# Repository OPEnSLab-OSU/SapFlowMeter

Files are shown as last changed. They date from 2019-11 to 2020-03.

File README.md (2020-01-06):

# Analysis of Sapflow Data

We are using python for post-processing and data analysis.

You should have the following installed:
- Python 3
- Pandas
- Numpy
- Matplotlib

You can find the recorded data at 
[web.engr.oregonstate.edu/~hornm/data/](http://web.engr.oregonstate.edu/~hornm/data/)

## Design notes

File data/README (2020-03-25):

This folder contains data from our sapflow probes.
In general, files that say "log" are temperature data, and files that say "sapflow" have calculated data.

tree1 is a spruce, with data captured using the MAX38165 RTD amplifier

tree4 is the same rhodedendron, using the MCP3432 ADC and a wheatstone bridge to get temeprature.

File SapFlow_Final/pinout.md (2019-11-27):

# Pinout of Feather M0 LoRa

**Left**

|Pin  |Signal|Peripheral|
|-----|---|---|
|RST  | Reset|
|3V | 3.3V | Voltage regulator |
|ARef | ARef | ADC |
|GND  |
|A0 |
|A1 |
|A2 |
|A3 |
|A4 |CS |MAX RTD sensor #2|
|A5 |CS |MAX RTD sensor #1|
|24 |SCK  |SPI|
|23 |MOSI |SPI|
|22 |MISO |SPI|
|0 |RX |Serial|
|1 |TX |Serial|
|DIO1 | ??? | LoRa |

**Right**

|Pin  |Signal|Peripheral|
|-----|---|---|
| 20 | SDA |I2C|
| 21 | SCL |I2C|
| 5  | 3.3_En| Power out (Pull low to enable)|
| 6  | 5v_En | Power out (Pull high to enable)|
| 9  |
| 10 | CS| SD Card on Hypno|
| 11 | Heat | Relay |
| 12 | RTC_interrupt |Real-time clock (used for alarms)|
| 13 | Status | LED |
| 5V | USB | Power in |
| En | Enable | Voltage Regulator |
| Bat| 3.7V | Battery |

**Pins dedicated to LoRa:**

|Pin  | Signal |
|-----|---|
|D3 | IRQ |
|D4 | RST |
|D8 | CS  |
|DIO1 | ??? |
|DIO2 | ??? |
|DIO3 | ??? |
|DIO5 | ??? |
Note: LoRa shares the SPI peripheral, but with a seperate chip select.

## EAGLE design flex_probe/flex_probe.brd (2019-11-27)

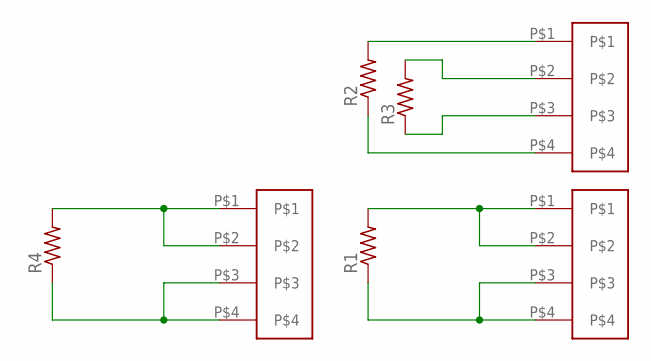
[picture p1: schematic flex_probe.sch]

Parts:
R1, R2, R3, R4: R-US_R0603; R0603
U$1, U$2, U$3: CONN_1X4; 4PAD

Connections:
unnamed: R1.2, U$1.P$1, U$1.P$2
unnamed: R1.1, U$1.P$3, U$1.P$4
unnamed: R2.1, U$2.P$4
unnamed: R3.2, U$2.P$2
unnamed: R3.1, U$2.P$3
unnamed: R2.2, U$2.P$1
unnamed: R4.2, U$3.P$1, U$3.P$2
unnamed: R4.1, U$3.P$3, U$3.P$4

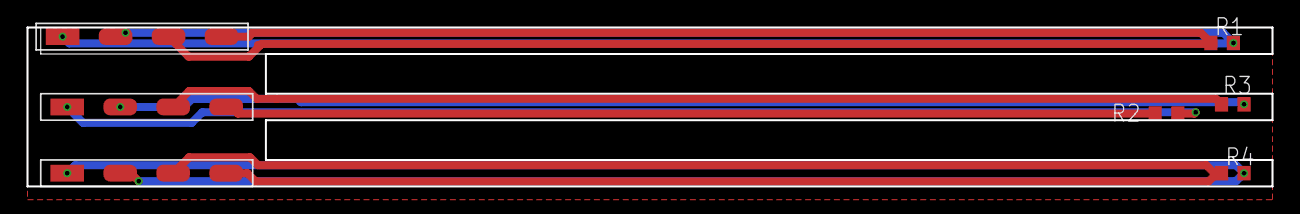
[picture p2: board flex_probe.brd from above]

Board: 2 copper layers, 94.0 x 12.0 mm, 7 parts (0 on the bottom side), 8 nets.

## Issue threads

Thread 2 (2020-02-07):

Need Error System

kamocat, 2020-02-07:
We need an error system on the feather, preferrably to post to Twitter.
Things we want to detect:
- SD card hanging
- Measurement errors (max and min temperature measured?)
- Bad reading from scale
- Low battery?
- Malformed JSON

kamocat, 2020-02-08:
We can use the watchdog timer to catch when things hang. The trick will be skipping a hanging function and continuing. Is there a way to have persistent variables after a watchdog reset? Or is there a way to return to a place different from where you started? ( Basically, save the stack pointer and skip over the problem function)

kamocat, 2020-02-08:
I'm envisioning a bitmask for each error, so known malfunctioning hardware will cause the appropriate function to be skipped.
For example, removing the SD card shouldn't cause the program to hang but should cause it to skip the steps for initializing the SD card. It should send a warning to Twitter about the issue.

prototypicalpro, 2020-02-10:
As you mentioned, the trick is exiting the function that hung without resetting the program. Greyston mentions this works on ARM: https://en.wikipedia.org/wiki/Setjmp.h , I'd be a bit scared to try it from an interrupt though. Another solution proposed by Atmel is writing your state to flash and then recovering it on reset: http://ww1.microchip.com/downloads/en/AppNotes/Atmel-42393-SAMD-Debugging-Watchdog-Timer-Reset_ApplicationNote_AT09381.pdf . This would also have the benefit of creating a "trace" of where the program failed.

kamocat, 2020-02-27:
Pull request #3 partially fixes this by providing a method for logging crashes.
We haven't yet implemented any sort of error reporting through Twitter, although this is our eventual goal.

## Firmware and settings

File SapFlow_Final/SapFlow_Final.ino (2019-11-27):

///////////////////////////////////////////////////////////////////////////////

// This program samples lots of temperature data from a tree to measure the sap flow.
///////////////////////////////////////////////////////////////////////////////

#define ALARM_PIN 12
#define HEATER 11

#include <OPEnS_RTC.h>
#include <LowPower.h>
#include <sdios.h> //for ArduinoOutStream

#include <SPI.h>
#include "SdFat.h"
#include "sdios.h"
#include <Adafruit_MAX31865.h>

Adafruit_MAX31865 rtd1 = Adafruit_MAX31865(A4);
Adafruit_MAX31865 rtd2 = Adafruit_MAX31865(A5);

#define RREF 430.0
#define RNOMINAL 100.0

ArduinoOutStream cout(Serial);

// Instance of our RTC
RTC_DS3231 rtc_ds;

// Time used for state transitions
volatile uint32_t event_time;

// SD chip select pin.  Be sure to disable any other SPI devices such as Enet.
const uint8_t chipSelect = 10;

// Interval between data records in milliseconds.
// The interval must be greater than the maximum SD write latency plus the
// time to acquire and write data to the SD to avoid overrun errors.
// Run the bench example to check the quality of your SD card.
const uint32_t SAMPLE_INTERVAL_MS = 1000;

SdFat sd; // File system object.

/* Checks if the filename exists.
* If so, appends an integer.
* Returns the new filename it came up with.*/
String newfile( String fname, String suffix=".csv" ){
  String temp = fname + suffix;
  int i = 0;
  while(sd.exists(temp.c_str())){
    ++i;
    char ones = i%10 + '0';
    char tens = i/10 + '0';
    temp = fname + '(' + tens + ones + ')' + suffix;
  }
  return temp;
}

// Stores samples and relative time.
// Adapt this datatype to your measurement needs.
class sample{
  private:
  float channel1;
  float channel2;
  DateTime t;

  public:
  sample( Adafruit_MAX31865 r1, Adafruit_MAX31865 r2 ){
    t = rtc_ds.now();
    r1.readRTD();
    r2.readRTD();
    channel1 = r1.temperature(RNOMINAL, RREF);
    channel2 = r2.temperature(RNOMINAL, RREF);
  }
  sample( size_t oversample ){
    t = rtc_ds.now();
    channel1 = 0;
    channel2 = 0;
    for( auto i = 0; i < oversample; ++i ){
      channel1 += analogRead(A0);
      channel2 += analogRead(A1);
    }
  }
  sample( void ){
    sample( 1 );
  }
  void print( ostream &stream){
    stream << t.text() << ", ";
    stream << setw(6) << channel1 << ", ";
    stream << setw(6) << channel2 << "\r\n";
  }
  // Print the header for a csv
  void header( ofstream &stream ){
    stream << setw(6) << "A0" << ',';
    stream << setw(6) << "A1" << '\n';
  }
  float channel(int num){
    if( num == 1 )
      return channel1;
    else
      return channel2;
  }
  DateTime time(void){
    return t;
  }
};

class datastream{
  private:
  String fname;
  ofstream sdout;
  bool file_open;

  public:
  datastream( String filename ){
    fname = filename;
  }
  void flush( void ){
    sdout.close();
    file_open = false;
  }
  void append( sample p ){
    if( !file_open ){
      sdout = ofstream( fname.c_str(), ios::out | ios::app );
      file_open = true;
    }
    p.print(sdout);
  }
};

//------------------------------------------------------------------------------

// Data storage object
datastream d("temperature_log.csv");

// Filename for calculated sap flow
String filename;
// File handle for the file
ofstream sapfile;

enum state{
  wake,
  heating,
  cooling,
  sleep
} measuring_state;

void alarmISR() {
  // Reset the alarm.
  rtc_ds.armAlarm(1, false);

  // Disable this interrupt
  detachInterrupt(digitalPinToInterrupt(ALARM_PIN));
  event_time = millis();
}

void feather_sleep( void ){
  while(!digitalRead(ALARM_PIN)){
    Serial.print("Waiting on alarm pin...");
    delay(10);
  }
  // Low-level so we can wake from sleep
  // I think calling this twice clears the interrupt.
  attachInterrupt(digitalPinToInterrupt(ALARM_PIN), alarmISR, LOW);
  attachInterrupt(digitalPinToInterrupt(ALARM_PIN), alarmISR, LOW);
  // Prep for sleep
  Serial.end();
  USBDevice.detach();
  // Disable SPI to save power
  pinMode(24, INPUT);
  pinMode(23, INPUT);
  pinMode(chipSelect, INPUT);
  // Turn off power rails
  digitalWrite(5, HIGH); digitalWrite(6, LOW);
  digitalWrite(LED_BUILTIN, LOW);
  // Sleep
  LowPower.standby();

  // Prep to resume
  digitalWrite(LED_BUILTIN, HIGH);
  digitalWrite(5, LOW); digitalWrite(6, HIGH);
  pinMode(24, OUTPUT);
  pinMode(23, OUTPUT);
  pinMode(chipSelect, OUTPUT);
  USBDevice.attach();
  Serial.begin(115200);
  sd.begin(chipSelect, SD_SCK_MHZ(1));
}

// Sleep until the time is a round multiple of the minute inteval.
// Produces unexpected bevahior for non-factors of 60 (7, 8, 9, 11, etc)
void sleep_cycle( int interval = 5 ){
  Serial.println("Sleeping until nearest multiple of 5 minutes");
  DateTime t = rtc_ds.now();
  t = t + TimeSpan( interval * 60 );
  uint8_t minutes = interval*(t.minute()/interval);
  rtc_ds.setAlarm(ALM2_MATCH_MINUTES, minutes, 0, 0);
  Serial.print("Alarm set to ");
  t = rtc_ds.getAlarm(2);
  Serial.println(t.text());
  delay(1000);
  feather_sleep();
}

void setup() 
{
  // Enable outputs to control 5V and 3.3V rails
  pinMode(5, OUTPUT); pinMode(6, OUTPUT);
  digitalWrite(5, LOW); digitalWrite(6, HIGH);
  pinMode(HEATER, OUTPUT);
  pinMode(ALARM_PIN, INPUT_PULLUP);
  digitalWrite(HEATER, LOW);
  measuring_state = wake;
  event_time = millis();
  
  Serial.begin(115200);
  Serial.println("Starting setup");

  // RTC Timer settings here
  if (! rtc_ds.begin()) {
    Serial.println("Couldn't find RTC");
  }
  // This may end up causing a problem in practice - what if RTC loses power in field? Shouldn't happen with coin cell batt backup
  if (rtc_ds.lostPower()) {
    Serial.println("RTC lost power, lets set the time!");
    // Set the RTC to the date & time this sketch was compiled
    rtc_ds.adjust(DateTime(F(__DATE__), F(__TIME__)));
  }
  
  Serial.println("Initializing SD Card");
  if (!sd.begin(chipSelect, SD_SCK_MHZ(1))) {
    sd.initErrorHalt();
  }

  // Make sure we're not overwriting an existing file.
  filename = newfile("sapflow");
  cout << "Creating new file " << filename.c_str() << "...";
  // Write the headers for the file
  sapfile = ofstream(filename.c_str(), ios::out);
  sapfile << "Date, Upper baseline, Lower baseline, Upper peak, Lower peak, calculated sapflow" << endl;
  sapfile.close();
  cout << "Success"<<endl;

  rtd1.begin(MAX31865_4WIRE);  // set to 2WIRE or 4WIRE as necessary
  rtd2.begin(MAX31865_4WIRE);  // set to 2WIRE or 4WIRE as necessary
  Serial.println("\n ** Setup Complete ** ");
  
  sleep_cycle();
}

float upper_baseline, lower_baseline;
float upper_peak, lower_peak, sapflow;
void loop() 
{
  sample s = sample(rtd1, rtd2); // Sample RTDs
  s.print(cout);
  d.append(s);  // Log to SD card
  if ((millis()-event_time) < 60000) {
    switch(measuring_state){
      case wake:
        Serial.print("Awoke at ");
        Serial.println(rtc_ds.now().text());
        // Sample for 3 seconds before heating
        event_time += 3000;
        measuring_state = heating;
        upper_baseline = s.channel(1);
        lower_baseline = s.channel(2);
        break;
      case heating:
        digitalWrite(HEATER, HIGH);
        Serial.print("Heater On at ");
        Serial.println(rtc_ds.now().text());
        //Set the alarm for heating time
        event_time += 6000;
        measuring_state = cooling;
        break;
      case cooling:
        digitalWrite(HEATER, LOW);
        Serial.print("Heater Off at ");
        Serial.println(rtc_ds.now().text());
        //set the alarm for cooling time
        event_time += 40000;
        measuring_state = sleep;
        break;
      default:
        // Make sure we're done logging
        d.flush();
        upper_peak = s.channel(1);
        lower_peak = s.channel(2);
        sapflow = log((upper_peak-upper_baseline)/(lower_peak-lower_baseline));
        // Write the sapflow to the file.
        sapfile = ofstream(filename.c_str(), ios::out | ios::app);
        sapfile << s.time().text() << ", ";
        sapfile << upper_baseline << ", ";
        sapfile << lower_baseline << ", ";
        sapfile << upper_peak << ", ";
        sapfile << lower_peak << ", ";
        sapfile << sapflow << endl;
        sapfile.close();
        //Sleep until the next 5-minute interval
        sleep_cycle( 5 );
        measuring_state = wake;
    }
  }
}

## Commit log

2019-11-27 Deployed in tree 11/26/2019
    Currently testing quality of measurements and calculations.
    [flex_probe.brd, flex_probe.sch]
2019-11-27 Made Python script for examining data from sapflow probe
2019-11-27 Changed formula for flow calculation.
2020-02-01 Fixed issues with sapflow calculation
    - Excluded data while the heater probe is on. The heater still seems to present electrical conduction issues for the RTDs.
    - Included upper and lower slope and baseline in processed data. This is useful for determining what the issues are that are causing wonky sapflow results.
2020-03-24 Added jupyter notebook for examining tree data
    [tree4_log.csv, tree4_sapflow.csv]
2020-03-24 Created data folder
    [tree3_sapflow.csv, tree4_log.csv, tree4_sapflow.csv]
2020-03-25 Started linear regression method.
    Decided tree3.csv didn't have any data worth keeping
    [tree3_sapflow.csv]
2020-05-01 Tested new data from field deployment
    [TRE~340C.CSV, TRE~D5CA.CSV, tree10_log.csv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]
2020-05-05 Added new data
    [tree1_log.csv, tree1_sapflow.csv, tree2_log.csv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]
